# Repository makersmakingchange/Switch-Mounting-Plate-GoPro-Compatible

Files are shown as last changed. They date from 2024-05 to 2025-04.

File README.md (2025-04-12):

<!--- Open Source Assistive Technology: GitHub Readme Template Version 1.1 (2024-Mar-15)  --->

<!--- TITLE Should match the name of the GitHub repository. Choose something descriptive rather than whimsical.  --->
# Switch Plate - GoPro Compatible

<!---  SUMMARY A brief summary of the project. What it does, who it is for, how much it costs.  --->
The Switch Plate - GoPro Compatible is a cost-effective option for mounting assistive switches. The Switch Plate has a flat surface to which an assistive switch can be attached using hook and loop fastener (e.g., VELCRO). The rear portion of the Switch Plate has a GoPro-compatible mounting interface so the mounting plate can be used with commercially available [GoPro](https://gopro.com/en/ca/) mounting accessories. 

This device is comprised of a single 3D printed part. The overall cost of materials is about $1. This does not include the cost of the GoPro-compatible mounting accessory and additional mounting hardware.

The Switch Plate - GoPro Compatible is open assistive technology (OpenAT). Under the terms of the open source licenses, the device may be built, used, and improved upon by anyone.

Last updated: 2024-May-27. 
The latest version is V1.0. This version has been built and is in use with at least one user.

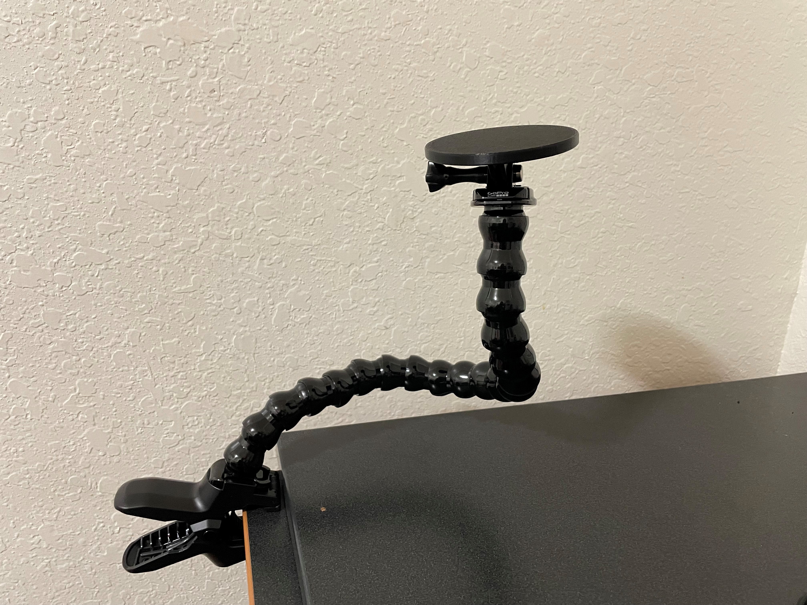
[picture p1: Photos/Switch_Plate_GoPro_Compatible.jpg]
A 3D printed Switch Plate - GoPro Compatible connected to a Loc-Line mount attached to a table.


## Makers Making Change Assistive Device Library
- https://www.makersmakingchange.com/s/product/switch-plate-(gopro-compatible)/01tJR000000TbKMYA0

## How to Obtain the Device
### 1. Do-it-Yourself (DIY) or Do-it-Together (DIT)

This is an open-source assistive technology, so anyone is free to build it. All of the files and instructions required to build the device are contained within this repository. Refer to the Maker Guide below.

### 2. Request a build of this device

You may also submit a build request through the [Makers Making Change Assistive Device Library Listing](<MMCWebLink>) to have a volunteer maker build the device. As the requestor, you are responsible for reimbursing the maker for the cost of materials and any shipping.

### 3. Build this device for someone else

If you have the skills and equipment to build this device, and would like to donate your time to create the device for someone who needs it, visit the [MMC Maker Wanted](https://makersmakingchange.com/maker-wanted/) section.

## Build Instructions

### 1. Read through the Maker Guide

The [Maker Guide](/Documentation/Switch_Plate_GoPro_Compatible_Maker_Guide.pdf) contains all the necessary information to build this device, including tool lists, assembly instructions, and testing.

### 2. Order the Off-The-Shelf Components

The [Bill of Materials](/Documentation/Switch_Plate_GoPro_Compatible_BOM.xlsx) lists the parts and components required to build the device.

### 3. Print the 3D Printable components

All of the files and individual print files can be in the [/Build_Files/3D_Printing_Files](/Build_Files/3D_Printing_Files/) folder.

### 4. Assemble the Switch Plate - GoPro Compatible

Reference the Assembly Guide section in the [Maker Guide](/Documentation/Switch_Plate_GoPro_Compatible_Maker_Guide.pdf) for the tools and steps required to build the device. 

## How to improve this Device
As open source assistive technology, you are welcomed and encouraged to improve upon the design. 

## Files
### Documentation
| Document | Version | Link |
|---|---|---|
| Design Rationale | 1.0 | [Switch_Plate_GoPro_Compatible_Design_Rationale](/Documentation/Switch_Plate_GoPro_Compatible_Design_Rationale.pdf) |
| Maker Guide | 1.0 | [Switch_Plate_GoPro_Compatible_Maker_Guide](/Documentation/Switch_Plate_GoPro_Compatible_Maker_Guide.pdf) |
| Bill of Materials | 1.0 | [Switch_Plate_GoPro_Compatible_Bill_of_Materials](/Documentation/Switch_Plate_GoPro_Compatible_BOM.csv) |
| User Guide | 1.0 | [Switch_Plate_GoPro_Compatible_User_Guide](/Documentation/Switch_Plate_GoPro_Compatible_User_Guide.pdf) |
| Changelog | 1.0 | [Changelog](CHANGES.txt) |

### Design Files
<!--- DESIGN FILES
Include a copy of the original design files to facilitate easy editing and customization. Consider also including a generic format (e.g., STEP)
--->
 - [CAD Files](/Design_Files/CAD_Design_Files)
<!--- - [PCB Files](/Design_Files/PCB_Design_Files) --->

<!--- BUILD FILES
Include a copy of the build files intended for manufacturing. This may include svg files for laser cutting, stl files for 3d printing, Gerber files for custom PCBs, and Arduino files for custom firmware
--->
### Build Files
 - [3D Printing Files](/Build_Files/3D_Printing_Files)
<!--- - [PCB Build Files](/Build_Files/PCB_Build_Files) --->
<!--- - [Firmware Files](/Build/Firmware_Files) --->

<!---
ATTRIBUTION
Provide any necessary attribution for designs or components that are included in the device or as part of the project.
--->
## Attribution

<!--- This is the attribution for the template. --->
The documentation template was created by Makers Making Change / Neil Squire Society and is used under a CC BY-SA 4.0 license. It is available at the following link: [https://github.com/makersmakingchange/OpenAT-Template](https://github.com/makersmakingchange/OpenAT-Template)

<!---
CONTRIBUTORS
List the names of the people that contributed to the design. This could include the original source of the idea, designers, testers, documenters, etc.
--->
### Contributors

 - Anna Millbourn. Design and photos.
 - Michael Camarda. Conceptualization and delivery.
 - Zoey Clontz. Conceptualization and delivery.
 - Dana Mumaw. Conceptualization and delivery.
 - Courtney Welch. Conceptualization and delivery.
 - Jake McIvor. Neil Squire Society / Makers Making Change. Documentation.

<!---
LICENSE
Add the year(s) for the copyright and the Designer Name. You may use the standard set of open licenses or choose your own for the hardware, software, and accompanying materials.
--->
## License
Design Copyright (c) 2024 Anna Millbourn. 

The design is made available using a [Creative Commons Attribution-ShareAlike 4.0 license (CC BY-SA 4.0)](https://creativecommons.org/licenses/by-sa/4.0/)

Documentation Copyright (c) 2024 Neil Squire Society.

Accompanying material such as instruction manuals, videos, and other copyrightable works that are useful but not necessary to design, make, test, or prepare the Switch Mount - GoPro Compatible are published under a [Creative Commons Attribution-ShareAlike 4.0 license (CC BY-SA 4.0)](https://creativecommons.org/licenses/by-sa/4.0/) .

Source Location: https://github.com/makersmakingchange/Switch-Mounting-Plate-GoPro-Compatible

----

<!-- ABOUT MMC START -->
## About Makers Making Change
[Makers Making Change Logo](https://www.makersmakingchange.com/)

Makers Making Change is a program of [Neil Squire](https://www.neilsquire.ca/), a Canadian non-profit that uses technology, knowledge, and passion to empower people with disabilities.

Makers Making Change leverages the capacity of community based Makers, Disability Professionals and Volunteers to develop and deliver affordable Open Source Assistive Technologies.

 - Website: [www.MakersMakingChange.com](https://www.makersmakingchange.com/)
 - GitHub: [makersmakingchange](https://github.com/makersmakingchange)
 - Bluesky: [@makersmakingchange.bsky.social](https://bsky.app/profile/makersmakingchange.bsky.social)
 - Instagram: [@makersmakingchange](https://www.instagram.com/makersmakingchange)
 - Facebook: [makersmakechange](https://www.facebook.com/makersmakechange)
 - LinkedIn: [Neil Squire Society](https://www.linkedin.com/company/neil-squire-society/)
 - Thingiverse: [makersmakingchange](https://www.thingiverse.com/makersmakingchange/about)
 - Printables: [MakersMakingChange](https://www.printables.com/@MakersMakingChange)

### Contact Us
For technical questions, to get involved, or to share your experience we encourage you to [visit our website](https://www.makersmakingchange.com/) or [contact us](https://www.makersmakingchange.com/s/contact).
<!-- ABOUT MMC END -->

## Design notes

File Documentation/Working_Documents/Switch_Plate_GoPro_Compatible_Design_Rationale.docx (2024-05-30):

# Introduction

This assistive switch mounting plate is ideal for individuals looking for a cost-effective way of mounting an assistive switch and hoping to utilize readily available GoPro mounting accessories.

This assistive switch mounting plate may be useful for those looking to mount an assistive switch and may include individuals with limited mobility of fine motor skills, such as those with disabilities, elderly users, or individuals recovering from injury.

# V1.0 Design

The Switch Plate – GoPro Compatible consists of a single 3d printed part with a flat narrow disc and a GoPro-compatible mounting interface on the bottom. The disc has an outer diameter of approximately 89 mm (3.5 in).

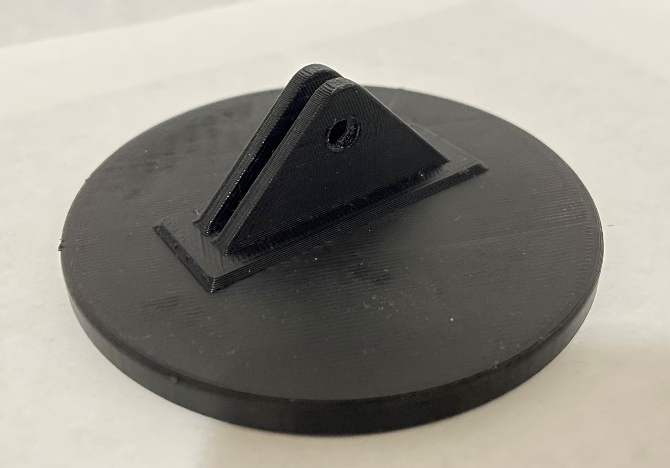
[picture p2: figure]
3D printed Switch Plate sitting upside down with triangular GoPro-compatible mounting finger interface sticking up.

Figure 1. Switch Plate - GoPro Compatible. Resting upside down.

The Switch Plate is sized for use with small Assistive Switches that have a flat bottom, such as the AbleNet Jelly Bean (https://www.ablenetinc.com/jelly-bean), or DIY OpenAT options like the Interact Switch (https://www.makersmakingchange.com/s/product/interact-switch/01tJR000000698vYAA) or the MMC60 Switch (https://www.makersmakingchange.com/s/product/mmc60-switch/01tJR000000693rYAA). The Assistive Switch is intended to be attached to the Switch Plate using hook and loop fastener (e.g., VELCRO) or double-sided adhesive.

The GoPro-compatible mounting interface has a similar shape and size to the mounting interface found on the bottom of a GoPro HERO camera or camera case. The two fingers are intended to engage with a variety of mounting solutions.

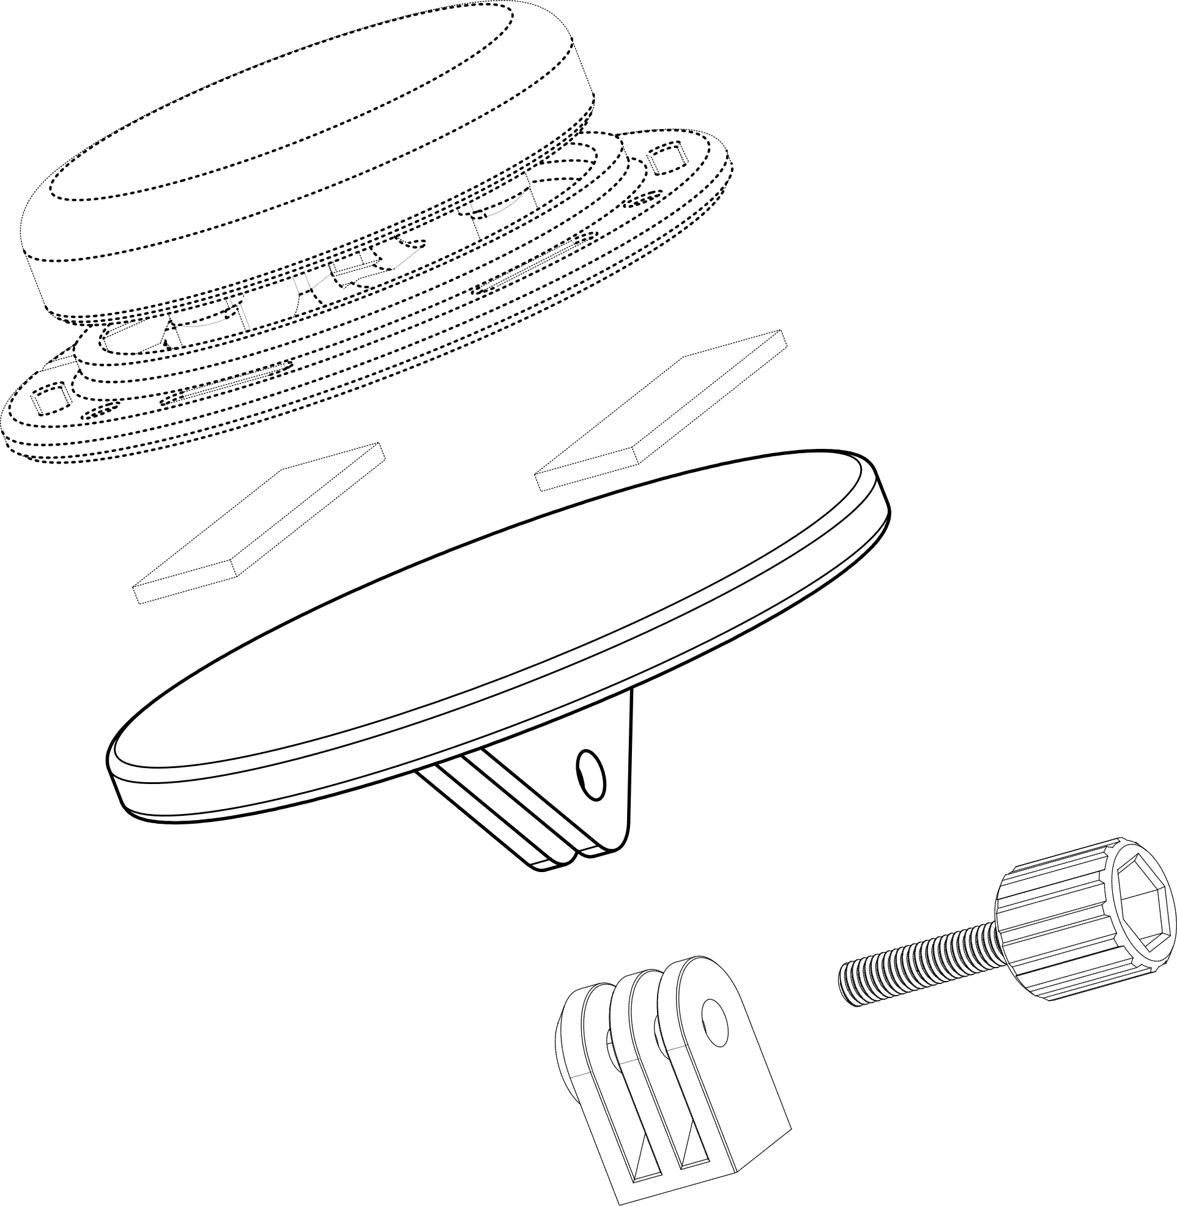
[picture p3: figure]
Assembly diagram of switch plate. Assistive switch is attached to top surface of Switch Plate using Hook and Loop or double-sided adhesive. A GoPro Finger Adaptor is attached to the bottom with a Thumb Screw.

Assistive Switch

Adhesive OR
Hook and Loop

GoPro Mounting Finger Adapter

Switch Plate

GoPro Thumb Screw

Figure 2. Switch Plate Assembly with Assistive Switch and GoPro Mounting Hardware.

GoPro Mounting Accessories uses a multi-fingered pivoting joint that is locked via friction applied by a fastener. The system uses an M5 machine screw or thumb screw, a 3-fingered mounting adapter, and a M5 locking hex nut.

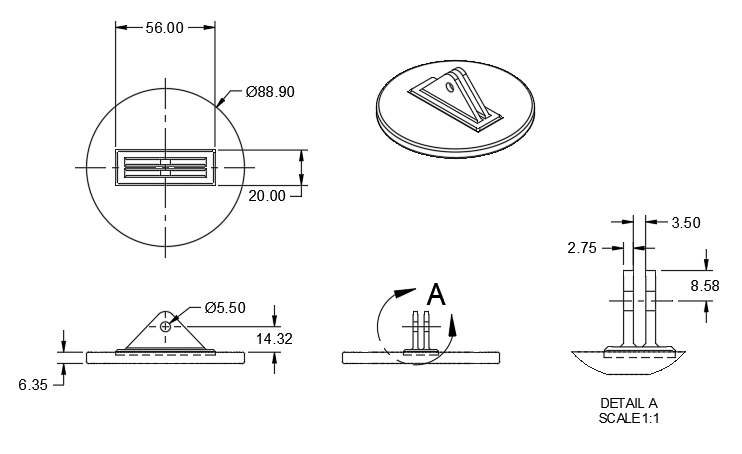
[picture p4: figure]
Switch Plate - GoPro Compatible. Key Dimensions.

Figure 3. Key Dimensions of Switch Plate.

## Mounting System Adapters

There is a range of GoPro compatible mounting hardware available commercially from GoPro and other vendors. There is also at least one open source 3D printable options for mounting components. Below is a non-exhaustive list of some of these solutions that are relevant for mounting assistive switches.

### GoPro

GoPro carries a variety of mounting solutions for mounting their cameras in a variety of applications. One example that is relevant for mounting assistive switches is the Jaws (https://gopro.com/en/ca/shop/mounts-accessories/jaws/ACMPM-001.html), which consist of a camera clamp mount and an and an adjustable neck. The adjustable neck appears to be similar to, and may consist of Loc-Line segments.

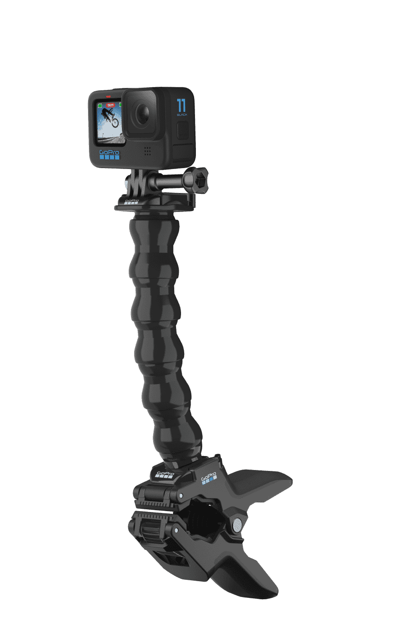
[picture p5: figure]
GoPro Jaws - Flex Clamp Camera Mount with Gooseneck Flexible Mount

Figure 4. GoPro Jaws. Copyright © 2024 GoPro, Inc.

### RAM

RAM Mounts are a modular mounting solution based on a ball-and-socket system that are commonly used to mount phones, tablets, and camera in a range of environments and applications. RAM has an Action Camera Universal Ball Adapter (https://rammount.com/products/rap-b-202u-gop1) that can be used to attach the Switch Plate to a standard B-sized 1” ball for use with other RAM mounting hardware.

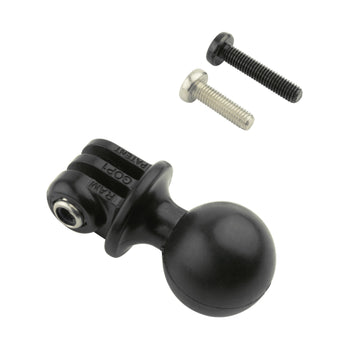
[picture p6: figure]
RAM<sup>®</sup> Action Camera Universal Ball Adapter

Figure 5. RAM Action Camera Universal Ball Adapter. Image Copyright ©2024 National Products Inc.

### Modular Mounting System

The Modular Mounting System was developed by Ryan Huang (HeyVye (https://www.thingiverse.com/HeyVye)) and released on Thingiverse (https://www.thingiverse.com/thing:2194278) under a Creative Commons – Attribution license (https://creativecommons.org/licenses/by/4.0/). It is a collection of modular mounting components that are also compatible with GoPro mounting accessories.

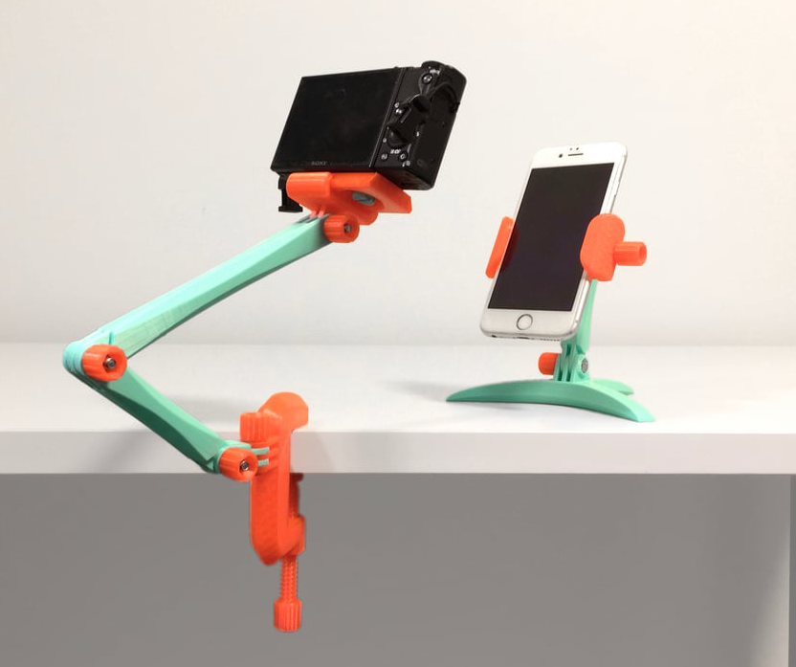
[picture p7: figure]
Carousel image representing the 3D design. Either an user-provided picture or a 3D render.

Figure 6. Modular Mounting System. Ryan Huang. CC-BY.

© 2024 by Neil Squire Society. This work is licensed under the CC BY SA 4.0 License: http://creativecommons.org/licenses/by-sa/4.0 Files available at https://github.com/makersmakingchange/Switch-Mounting-Plate-GoPro-Compatible Page 1 of 1

V1.0 | MAY 2024 Switch Plate - GoPro Compatible Design Rationale

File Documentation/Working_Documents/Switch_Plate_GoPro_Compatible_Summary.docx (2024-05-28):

This document is intended to be a summary of a device to make it easier to add to the website.

# Product Information

## Product Name

Switch Plate - GoPro Compatible

## Device Category

Mark any relevant categories with an “X”:

| Adapted Toys
| Aids for Daily Living (ADL)
| Assistive Switches
| Communication Aids (AAC)
| Computer Access
| Environmental Controls
| Gaming
| Keyguard
| Kits
| LipSyncs
X | Mounting
| Recreation and Leisure
| Seating and Positioning
| Switch Interfaces
| Writing Aids

## User Value Statement

A cost-effective option for mounting assistive switches with a GoPro-compatible mounting interface.

## Designer

Anna Millbourn

# Device Info

## Overview

This assistive switch mounting plate is ideal for individuals looking for a cost-effective way of mounting an assistive switch and hoping to utilize readily available GoPro mounting accessories.

## Disability Type

Select one or more disability types and mark with an “X”:

X | Agility / Dexterity
| Arthritis
X | Cognitive
| Hearing
X | Mobility
| Pain
| SCI
X | Vision
| Other

## Disability Type Description

This assistive switch mounting plate may be useful for those looking to mount an assistive switch and may include individuals with limited mobility of fine motor skills, such as those with disabilities, elderly users, or individuals recovering from injury.

## How To Use

The two-finger mounting interface on the back of the Switch Plate ins inserted into the three fingers of the GoPro Mounting Finger Adapter and secured with the GoPro Thumb Screw.

The Assistive Switch is attached to the top surface of the Switch Plate using hook and loop fastener (e.g., VELCRO) or double-sided adhesive.

## Estimated Cost

The estimated material cost of the device for a single build:

X | $0 - $10
| $11 - $25
| $26 - $50
| $51 - $100
| $101 - $250
| $250+

## Attribution

Designed by Anna Millbourn.

Documentation by Neil Squire Society / Makers Making Change.

# Maker Info

## Project Skills

Mark the required project skills with an “X”:

X | 3D Printing
| Custom PCB
| Electronics
| Laser Cutting
| Mechanics
| Software
| Soldering
| Woodworking
| Other

## Skills Description

This device requires basic 3D printing skills and some minor mechanical assembly.

## Tools Needed

X | 3D Printer
| Common Hand Tools
| Common Power Tools
| Laser Cutter
| Soldering Iron
| Specialized Tooling

## Print time (hrs)

3:00

## Assembly time (hrs)

0:15

## Build Instructions

This is a simple build that involve a single 3D printed component.

## Download Link

https://github.com/makersmakingchange/Switch-Mounting-Plate-GoPro-Compatible/archive/refs/heads/main.zip

## Project Link

## https://github.com/makersmakingchange/Switch-Mounting-Plate-GoPro-Compatible

# License

## License

Hardware: CC BY-SA

Software: n/a

Documentation: CC BY-SA

© 2024 by Neil Squire Society. This work is licensed under the CC BY SA 4.0 License: http://creativecommons.org/licenses/by-sa/4.0 Page 1 of 2

V1.0 | MAY 2024 Switch Plate - GoPro Compatible Summary

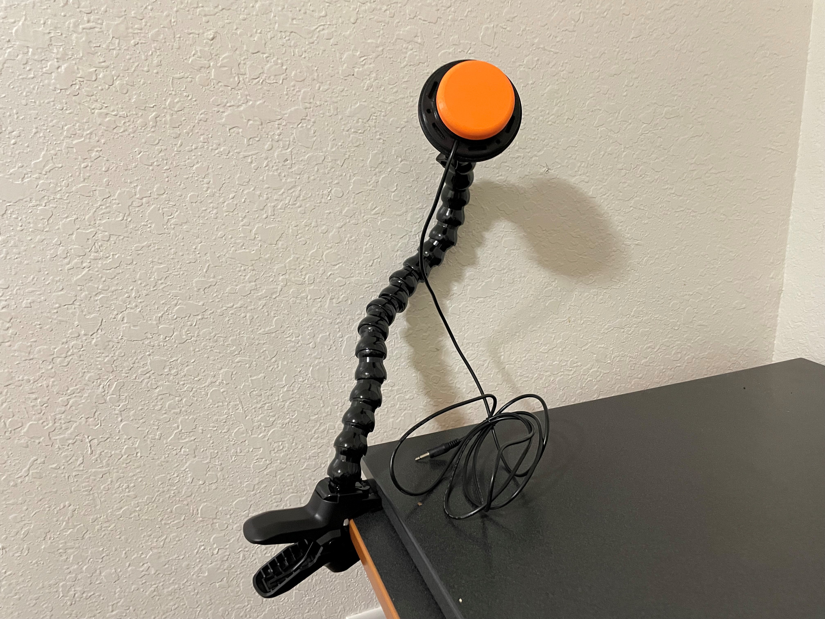
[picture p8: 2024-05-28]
Photos/Switch_Plate_GoPro_Compatible_Switch.jpg

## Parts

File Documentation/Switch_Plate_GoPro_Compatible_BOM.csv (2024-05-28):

Switch Plate - GoPro Compatible |  | Total Cost | Total Print time (hr) | Total filament (g)
Version: V1.0 | Last updated: 2024-May-27 | $0.63 | 0.00 | 25
Commercial Parts
Part type (Electrical. Mechanical, Sanitization, etc) | Part Name | Quantity Needed | Pkg Quantity | Price per package | Price per Unit | Price for qty needed | Link
 |  |  |  |  | $- | $-
3D Printed Parts ESTIMATED PRICING USING 1KG ROLL COST: | $25.00
Part | Description | Quantity Needed | TOTAL Mass (g) | Estimated Price | Print Time (Min) | Link
Switch_Plate_GoPro_Compatible.stl |  | 1 | 25 | $0.63 | 00:55
 |  |  |  | $-
 |  |  |  | $-
 |  |  |  | $-
 |  |  | Total Print Cost: | $0.63
Tools for Assembly
Alternatives (if there are other sources for some parts link them below)
Part and description | Link
RAM Action Camera Universal Ball Adapter | https://rammount.com/products/rap-b-202u-gop1

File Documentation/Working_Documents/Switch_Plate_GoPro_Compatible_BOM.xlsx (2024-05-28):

Switch Plate - GoPro Compatible |  | Total Cost | Total Print time (hr) | Total filament (g)
Version: V1.0 | Last updated: 2024-May-27 | $0.62 | 0.00 | 25
Commercial Parts
Part type (Electrical. Mechanical, Sanitization, etc) | Part Name | Quantity Needed | Pkg Quantity | Price per package | Price per Unit | Price for qty needed | Link
 |  |  |  |  | $0.00 | $0.00
3D Printed Parts ESTIMATED PRICING USING 1KG ROLL COST: | $25.00
Part | Description | Quantity Needed | TOTAL Mass (g) | Estimated Price | Print Time (Min) | Link
Switch_Plate_GoPro_Compatible.stl |  | 1 | 25 | $0.62 | 00:55
 |  |  |  | $0.00
 |  |  |  | $0.00
 |  |  |  | $0.00
 |  |  | Total Print Cost: | $0.62
Tools for Assembly
Alternatives (if there are other sources for some parts link them below)
Part and description | Link
RAM Action Camera Universal Ball Adapter | https://rammount.com/products/rap-b-202u-gop1

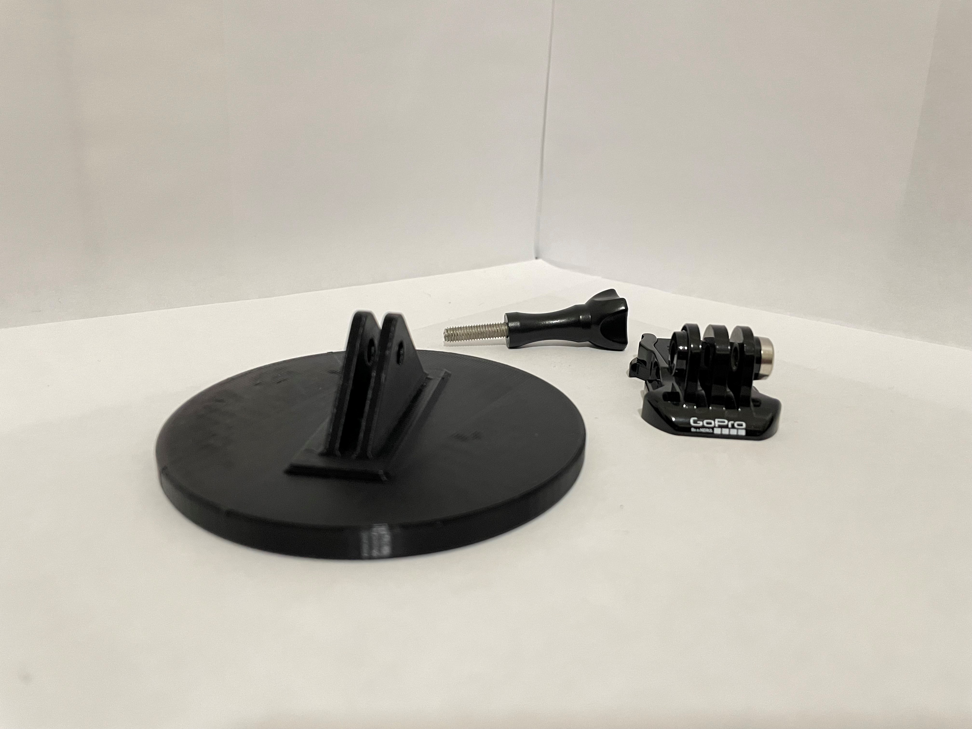
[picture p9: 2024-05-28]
Photos/Switch_Plate_GoPro_Compatible_Parts.jpg

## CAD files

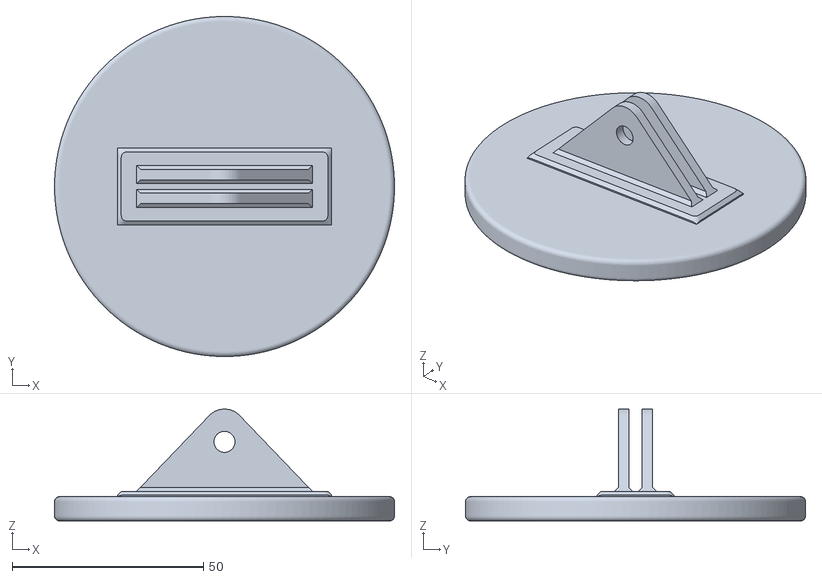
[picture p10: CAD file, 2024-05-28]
Build_Files/3D_Printing_Files/Switch_Plate_GoPro_Compatible.stl
88.9 x 88.9 x 29.2

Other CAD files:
Design_Files/CAD_Design_Files/STEP/Switch_Plate_GoPro_Compatible.step
Design_Files/CAD_Design_Files/Autodesk_Fusion/Switch_Plate_GoPro_Compatible.f3z

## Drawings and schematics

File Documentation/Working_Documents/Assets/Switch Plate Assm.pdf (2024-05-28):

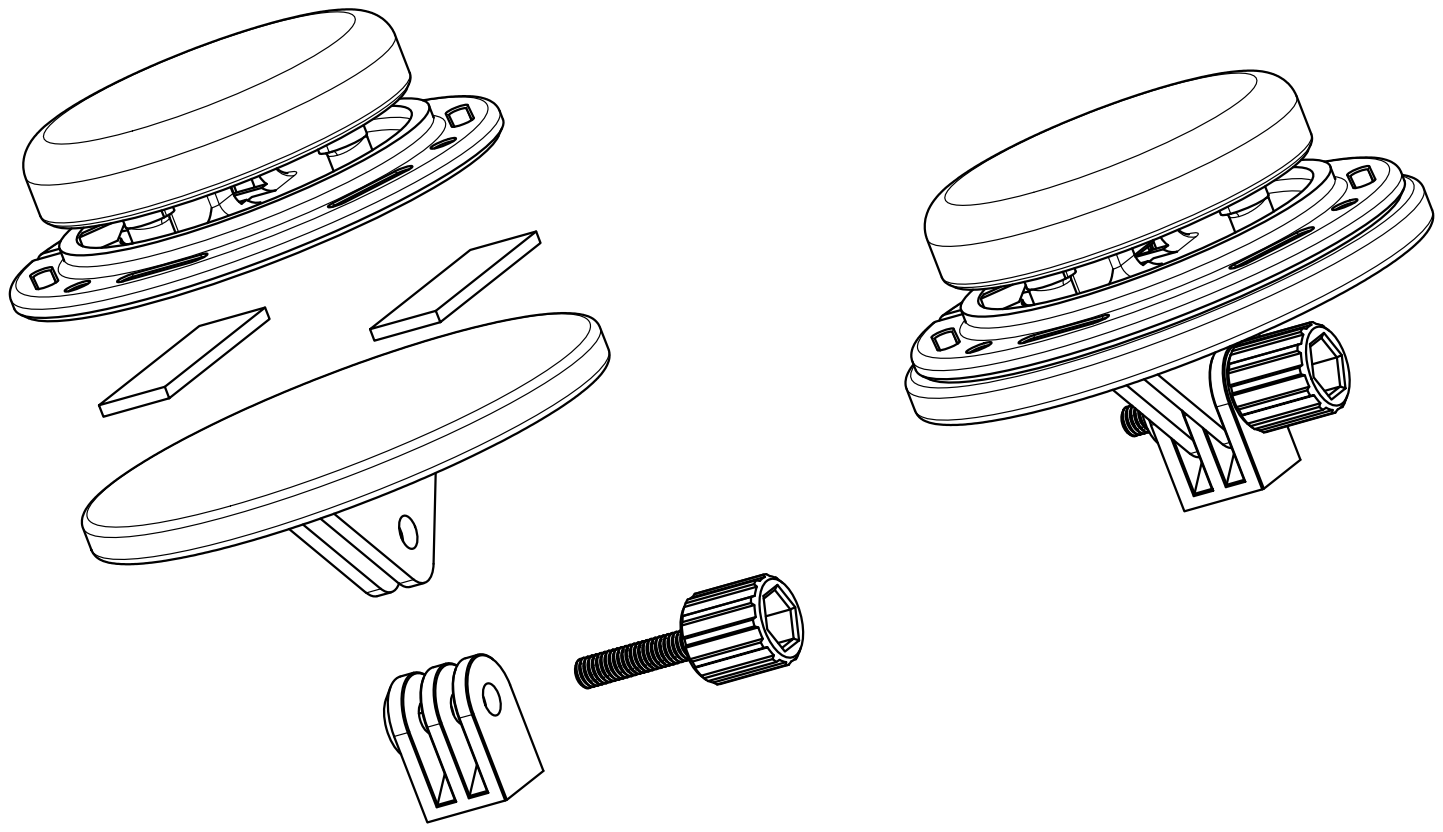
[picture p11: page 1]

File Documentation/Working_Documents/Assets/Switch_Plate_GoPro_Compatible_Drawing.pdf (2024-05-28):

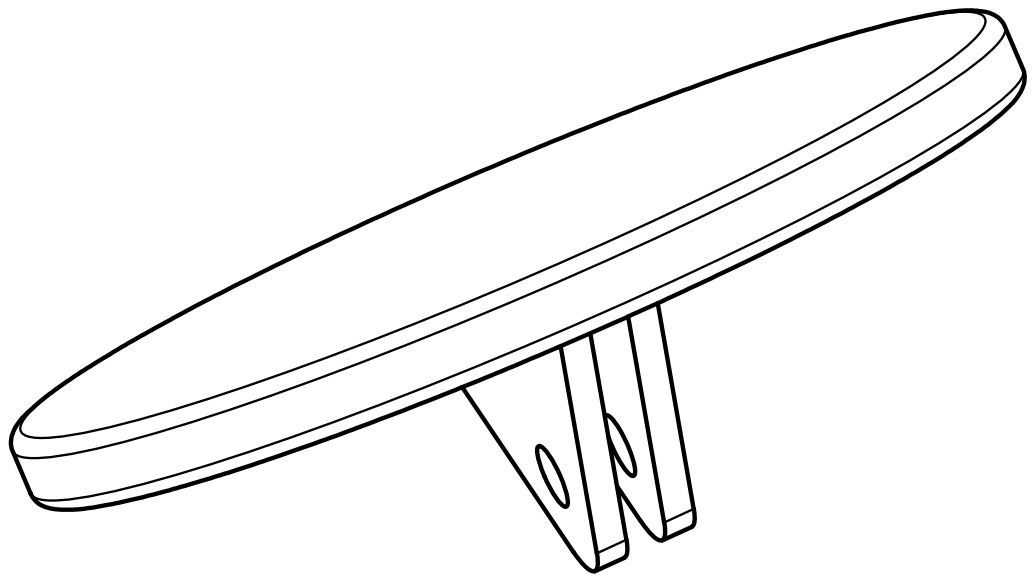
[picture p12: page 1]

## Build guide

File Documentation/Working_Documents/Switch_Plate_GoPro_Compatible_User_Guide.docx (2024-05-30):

## Introduction

This mounting plate is ideal for individuals looking for a cost-effective way of mounting an assistive switch and hoping to utilize readily available GoPro mounting accessories.

## Features

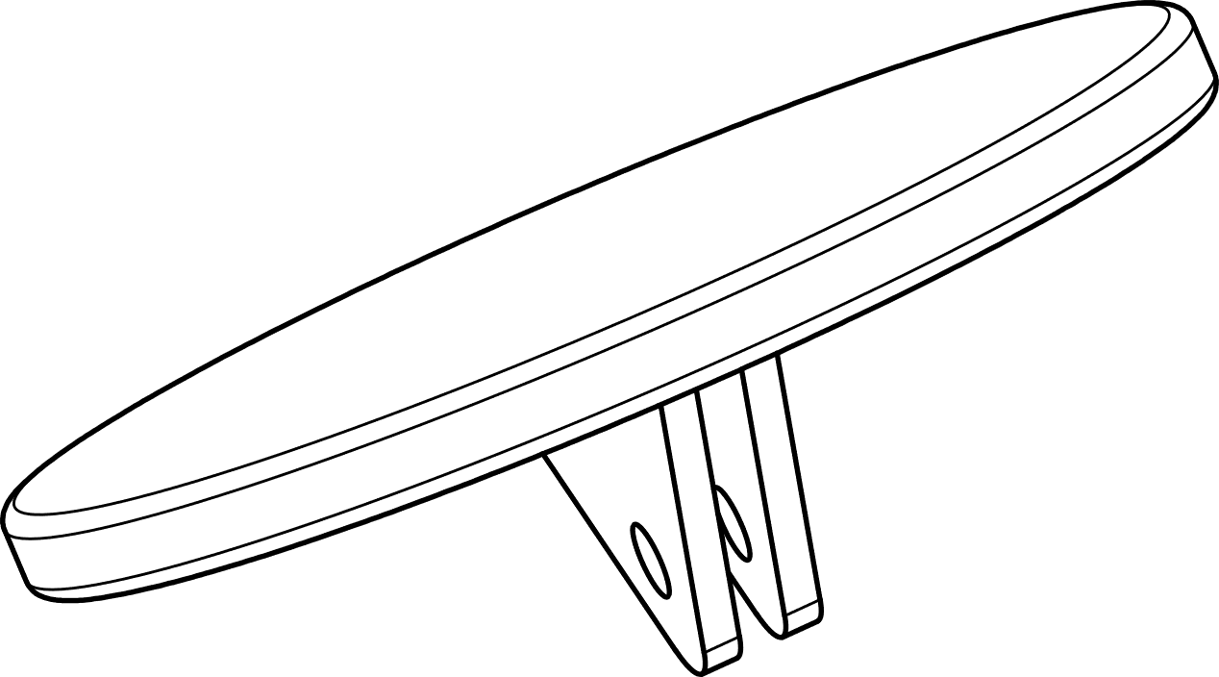
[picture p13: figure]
Line drawing of angled view of Switch Plate showing Assistive Switch Mounting surface and GoPro-compatible mounting fingers.

Assistive Switch Mounting Surface

GoPro-compatible Mounting Interface

## Specifications

Diameter | Ø89 mm (Ø3.5 inch)
Mass | 25 g (Switch Plate Only)

## Compatibility

### Assistive Switches

The Switch Plate – GoPro Compatible is compatible with Assistive Switches that can be mounted to a flat surface. This includes commercial options like AbleNet Jelly Bean and DIY OpenAT options like the Interact Switch and MMC 60 Switch.

### Mounting

The Switch Plate – GoPro Compatible is compatible with mounting accessories that have a three-fingered mounting adapter.

## Usage

### Connecting to GoPro Mounting Accessory

The two-finger mounting interface on the back of the Switch Plate is inserted into the three fingers of the GoPro Mounting Finger Adapter and secured with the GoPro Thumb Screw.

### Attaching Assistive Switch

Attach the Assistive Switch to the Mounting Surface of the Switch Plate using hook and loop fastener (e.g., VELCRO) or double-sided adhesive.

Assembly diagram of switch plate. Assistive switch is attached to top surface of Switch Plate using Hook and Loop or double-sided adhesive. A GoPro Finger Adaptor is attached to the bottom with a Thumb Screw.

Assistive Switch

Adhesive OR
Hook and Loop

GoPro Mounting Finger Adapter

Switch Plate

GoPro Thumb Screw

## Cleaning

The Switch Plate can be cleaned with a damp cloth. The Switch Plate can also be cleaned by scrubbing with warm water and dish soap. Do not expose to hot water or a dishwasher. Do not use harsh cleaners.

© 2024 by Neil Squire Society. This work is licensed under the CC BY SA 4.0 License: http://creativecommons.org/licenses/by-sa/4.0 Files available at https://github.com/makersmakingchange/Switch-Mounting-Plate-GoPro-Compatible Page 2 of 3

V1.0 | MAY 2024 Switch Plate - GoPro Compatible user Quick Guide

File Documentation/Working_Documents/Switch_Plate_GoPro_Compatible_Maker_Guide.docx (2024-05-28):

# Overview

This document contains the necessary information to build the device.

# Maker Checklist

This list provides an overview of the steps required to build and deliver the device.

## Maker To Do List

- Read through the Maker Guide to become familiar with required components, tools, supplies, and safety gear and overall assembly steps.
- Talk to User about customization options (e.g., color, any special requests, etc.)
- Confirm with user whether they already have a GoPro mounting accessory or which one they need.
- 3D print the device
- Print “User Guide”

## Items to Give to User

- Assembled, tested device
- “User Guide”

# Tool List

(No tools are required for this device)

# Customization Guide

The Switch Plate can be printed in the user’s desired colour.

# 3D Printing Guide

## 3D Printing Summary

Metrics | Single Unit
Total Print Time (min) | 3h
Total Number of Components | 1
Typical Total Mass (g) | 25
Typical Number of Print Setups | 1

## 3D Printing Settings

Print File Name | Qty | Total Print Time (hr:min) | Mass (g) | Infill (%) | Support(Y/N) | Layer Height/ Nozzle Diameter(mm) | Notes
Switch_Plate_GoPro_Compatible.stl | 1 | 3:00 | 25 | 15 | N | 0.2/0.4

## Post-Processing

- Remove any blobs or zits
- Ensure all edges are smooth.

# Assembly Guide

(This device does not require assembly)

Refer to the User Guide for instruction on how to attach an Assistive Switch and how to attach a GoPro-compatible mounting hardware.

© 2024 by Neil Squire Society. This work is licensed under the CC BY SA 4.0 License: http://creativecommons.org/licenses/by-sa/4.0 Files available at https://github.com/makersmakingchange/Switch-Mounting-Plate-GoPro-Compatible Page 1 of 1

V1.0 | MAY 2024 Switch Plate - GoPro Compatible maker Guide

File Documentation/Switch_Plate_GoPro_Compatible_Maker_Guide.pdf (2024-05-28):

V1.0 | MAY 2024

## Switch Plate - GoPro Compatible

## MAKER GUIDE

© 2024 by Neil Squire Society. (https://neilsquire.ca/) This work is licensed under the CC BY SA 4.0 License: http://creativecommons.org/licenses/by-sa/4.0
Files available at https://github.com/makersmakingchange/Switch-Mounting-Plate-GoPro-Compatible | Page 1 of 6

### Overview

This document contains the necessary information to build the device.

### Contents

## MAKER GUIDE

Files available at https://github.com/makersmakingchange/Switch-Mounting-Plate-GoPro-Compatible | Page 2 of 6

### Maker Checklist

This list provides an overview of the steps required to build and deliver the device.

### Maker To Do List

Read through the Maker Guide to become familiar with required components, tools, supplies, and safety gear and overall assembly steps.
Talk to User about customization options (e.g., color, any special requests, etc.)
Confirm with user whether they already have a GoPro mounting accessory or which one they need.
3D print the device
Print “User Guide”

### Items to Give to User

Assembled, tested device
“User Guide”

## MAKER GUIDE

Files available at https://github.com/makersmakingchange/Switch-Mounting-Plate-GoPro-Compatible | Page 3 of 6

### Tool List

(No tools are required for this device)

## MAKER GUIDE

Files available at https://github.com/makersmakingchange/Switch-Mounting-Plate-GoPro-Compatible | Page 4 of 6

### Customization Guide

The Switch Plate can be printed in the user’s desired colour.

## MAKER GUIDE

Files available at https://github.com/makersmakingchange/Switch-Mounting-Plate-GoPro-Compatible | Page 5 of 6

### 3D Printing Guide

### 3D Printing Summary

Metrics | Single Unit
Total Print Time (min) | 3h
Total Number of Components | 1
Typical Total Mass (g) | 25
Typical Number of Print Setups | 1

### 3D Printing Settings

Print File Name | Qty | Total Print Time (hr:mi n) | M as s (g ) | Infil l (%) | Support(Y/ N) | Layer Height/ Nozzle Diameter(m m) | Notes
Switch_Plate_GoPro_Comp atible.stl | 1 | 3:00 | 25 | 15 | N | 0.2/0.4

### Post-Processing

- Remove any blobs or zits
- Ensure all edges are smooth.

## MAKER GUIDE

Files available at https://github.com/makersmakingchange/Switch-Mounting-Plate-GoPro-Compatible | Page 6 of 6

### Assembly Guide

(This device does not require assembly)

Refer to the User Guide for instruction on how to attach an Assistive Switch and how to attach a GoPro-compatible mounting hardware.

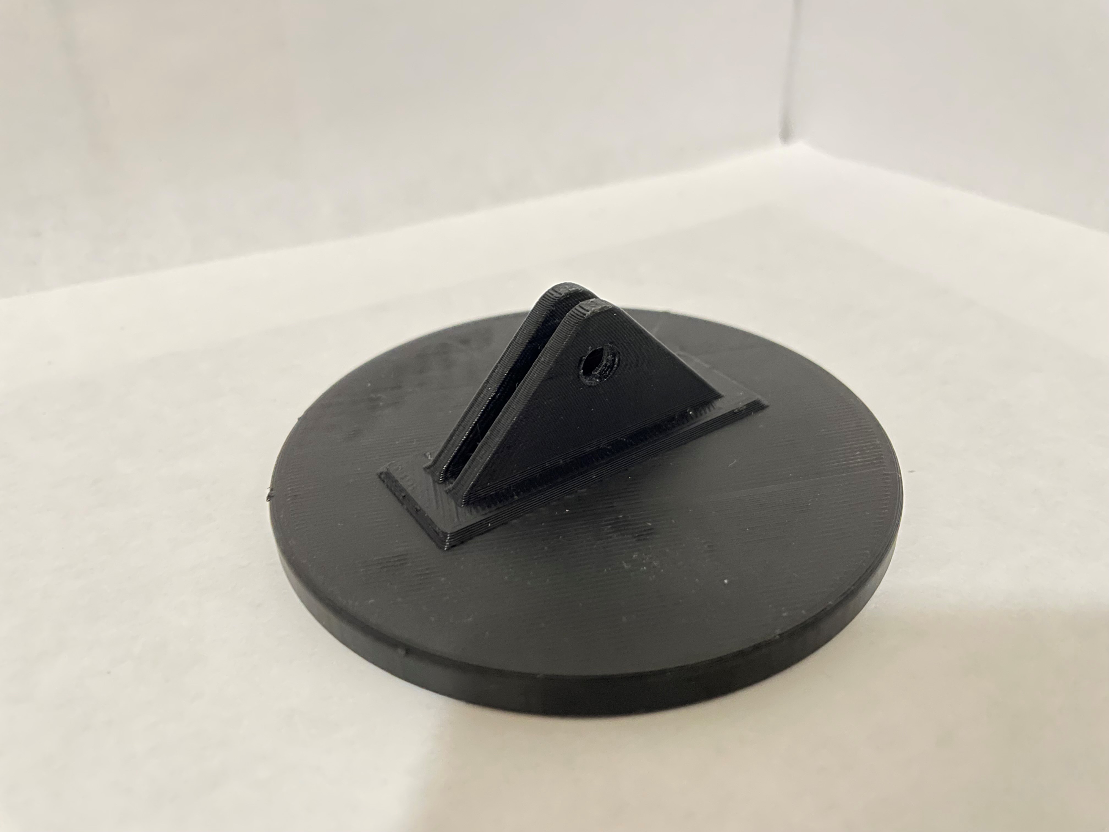
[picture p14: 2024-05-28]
Photos/Switch_Plate_GoPro_Compatible_Print.jpg

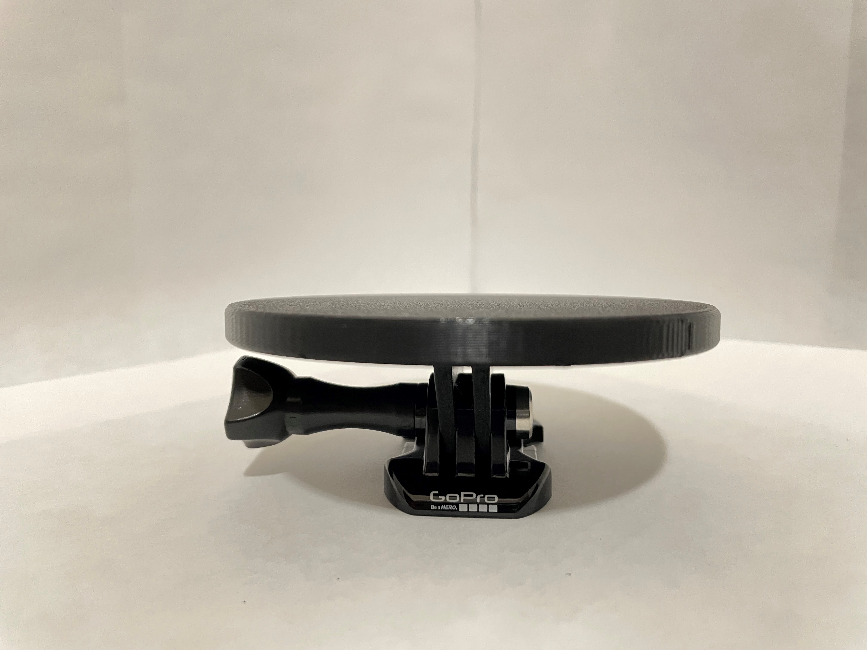
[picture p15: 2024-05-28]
Photos/Switch_Plate_GoPro_Compatible_Assembled.jpg

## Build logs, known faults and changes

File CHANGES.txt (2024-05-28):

Version 1.0 | 2024-May-27
 - Initial release, including design files, print files, and photos
 - Initial documentation including BOM, Maker Guide, User Guide, and Summary
